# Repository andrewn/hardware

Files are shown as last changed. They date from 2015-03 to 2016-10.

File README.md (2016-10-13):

This repository contains a laser cutter template for a Radiodan case. 
See the `case` directory for the usage license and instructions.

It also contains the PCB design for Radiodan. Under the Gerber_Files 
directory are oshpark-radiodan and dirty-pcb-radiodan which we've 
successfully had made by OshPar and DirtyPCB respspectively.

Under the BOM directory are pdf and csv version of the Radiodan Bill of 
Materials as of October 2016.

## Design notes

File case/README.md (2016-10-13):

Case
----

A case suitable for laser cutter for making your own [radiodan](http://radiodan.net) case.

Photo of Radiodan case

The case is designed to be laser cut out of 3mm thickness material.

Our current recommendation is to use the wide case format, with [this BOM](https://github.com/radiodan/hardware/tree/master/bom).

We've used the following colours:

| Colour  | Action |
|---|---|
| RED | Cut |
| BLUE | Score  |
| BLACK | Etch |

[Follow our instructions](http://radiodan.net/help/tutorials/make-a-case.html) to put it all together.

Feedback
---

If you have any feedback or suggestions to make this design easier to use with a laser cutter then please [raise an issue](https://github.com/radiodan/hardware/issues).

License and adaptations
---

Please see [LICENSE](LICENSE.txt) for the terms about how you can use this design.

Credits
---

The case was designed by [Victor Johansson](https://twitter.com/victordons).

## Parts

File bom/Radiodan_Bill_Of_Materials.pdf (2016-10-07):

Radiodan Bill of Materials
2016-10-07
Description | RS code | Number | Part number | Link
26 PIN BOXED HEADER, VERTICAL, LOW PROFILE 461-786 | | 1 | THOMAS&BETTS 609-2627
RESISTOR,1%,120 ohm, MRS25, 683-2979 | | 2 | VISHAY BC COMPONENTS MRS25000C1200FCT00
RESISTOR,1%,68 ohm,MRS25, 683-3950 | | 4 | VISHAY BC COMPONENTS MRS25000C6809FCT00
SWITCH, MECHANICAL KEY686-6768 | | 1 | OMRON B3F-4050
SWITCH CAP,ROUND,BLACK682-1115 | | 1 | OMRON B32-1610
Raspberry PI 3 | 896-8660 | 1
8GB SD card | 917-6317 | 1
Power supply (2.5A) | 103-4302 | 1
ROTARY ENCODER - ILLUMINATED | | 2 | PPCOM-10982
Rotary encoder cap | | 2 | PPCOM-10597
GPIO downgrade ribbon cable | | 1 | | https://www.coolcomponents.co.uk/downgrade-gpio-ribbon-cable-for-raspberry-pi-model-b-40p-to-26p.html
DAC | | 1 | | https://shop.pimoroni.com/products/phat-dac
Speaker | | 1 | | https://www.amazon.co.uk/Veho-VSS-001-360-Portable-Rechargeable-Smartphones-Black/dp/B002CS2T4I
Extra tall stackable headers | | 1 | | https://www.coolcomponents.co.uk/stackable-header-20-pin.html
4cm length (minimum) bolts, 4mm diameter | | 4
Wingnuts | | 4
Sticky velcro | | a little | | http://www.ebay.co.uk/bhp/self-adhesive-velcro
Laser cut case | | 1 | | https://github.com/radiodan/hardware/tree/master/case
PCB | | 1 | | https://github.com/radiodan/hardware/tree/master/pcb

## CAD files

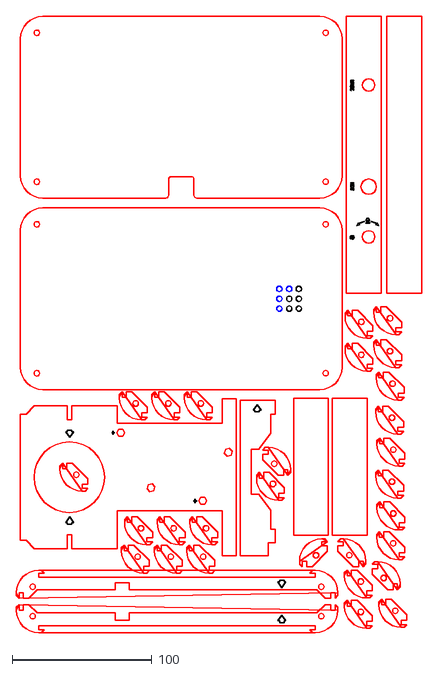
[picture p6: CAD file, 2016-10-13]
case/3mm Single Case - 0.25pt cut lines.dxf
290.0 x 440.7

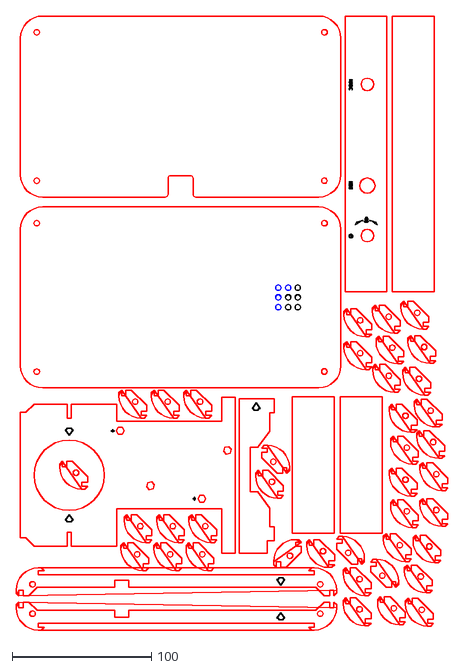
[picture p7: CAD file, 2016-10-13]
case/wide 3mm Single Case - 0.25pt cut lines.dxf
309.8 x 440.7

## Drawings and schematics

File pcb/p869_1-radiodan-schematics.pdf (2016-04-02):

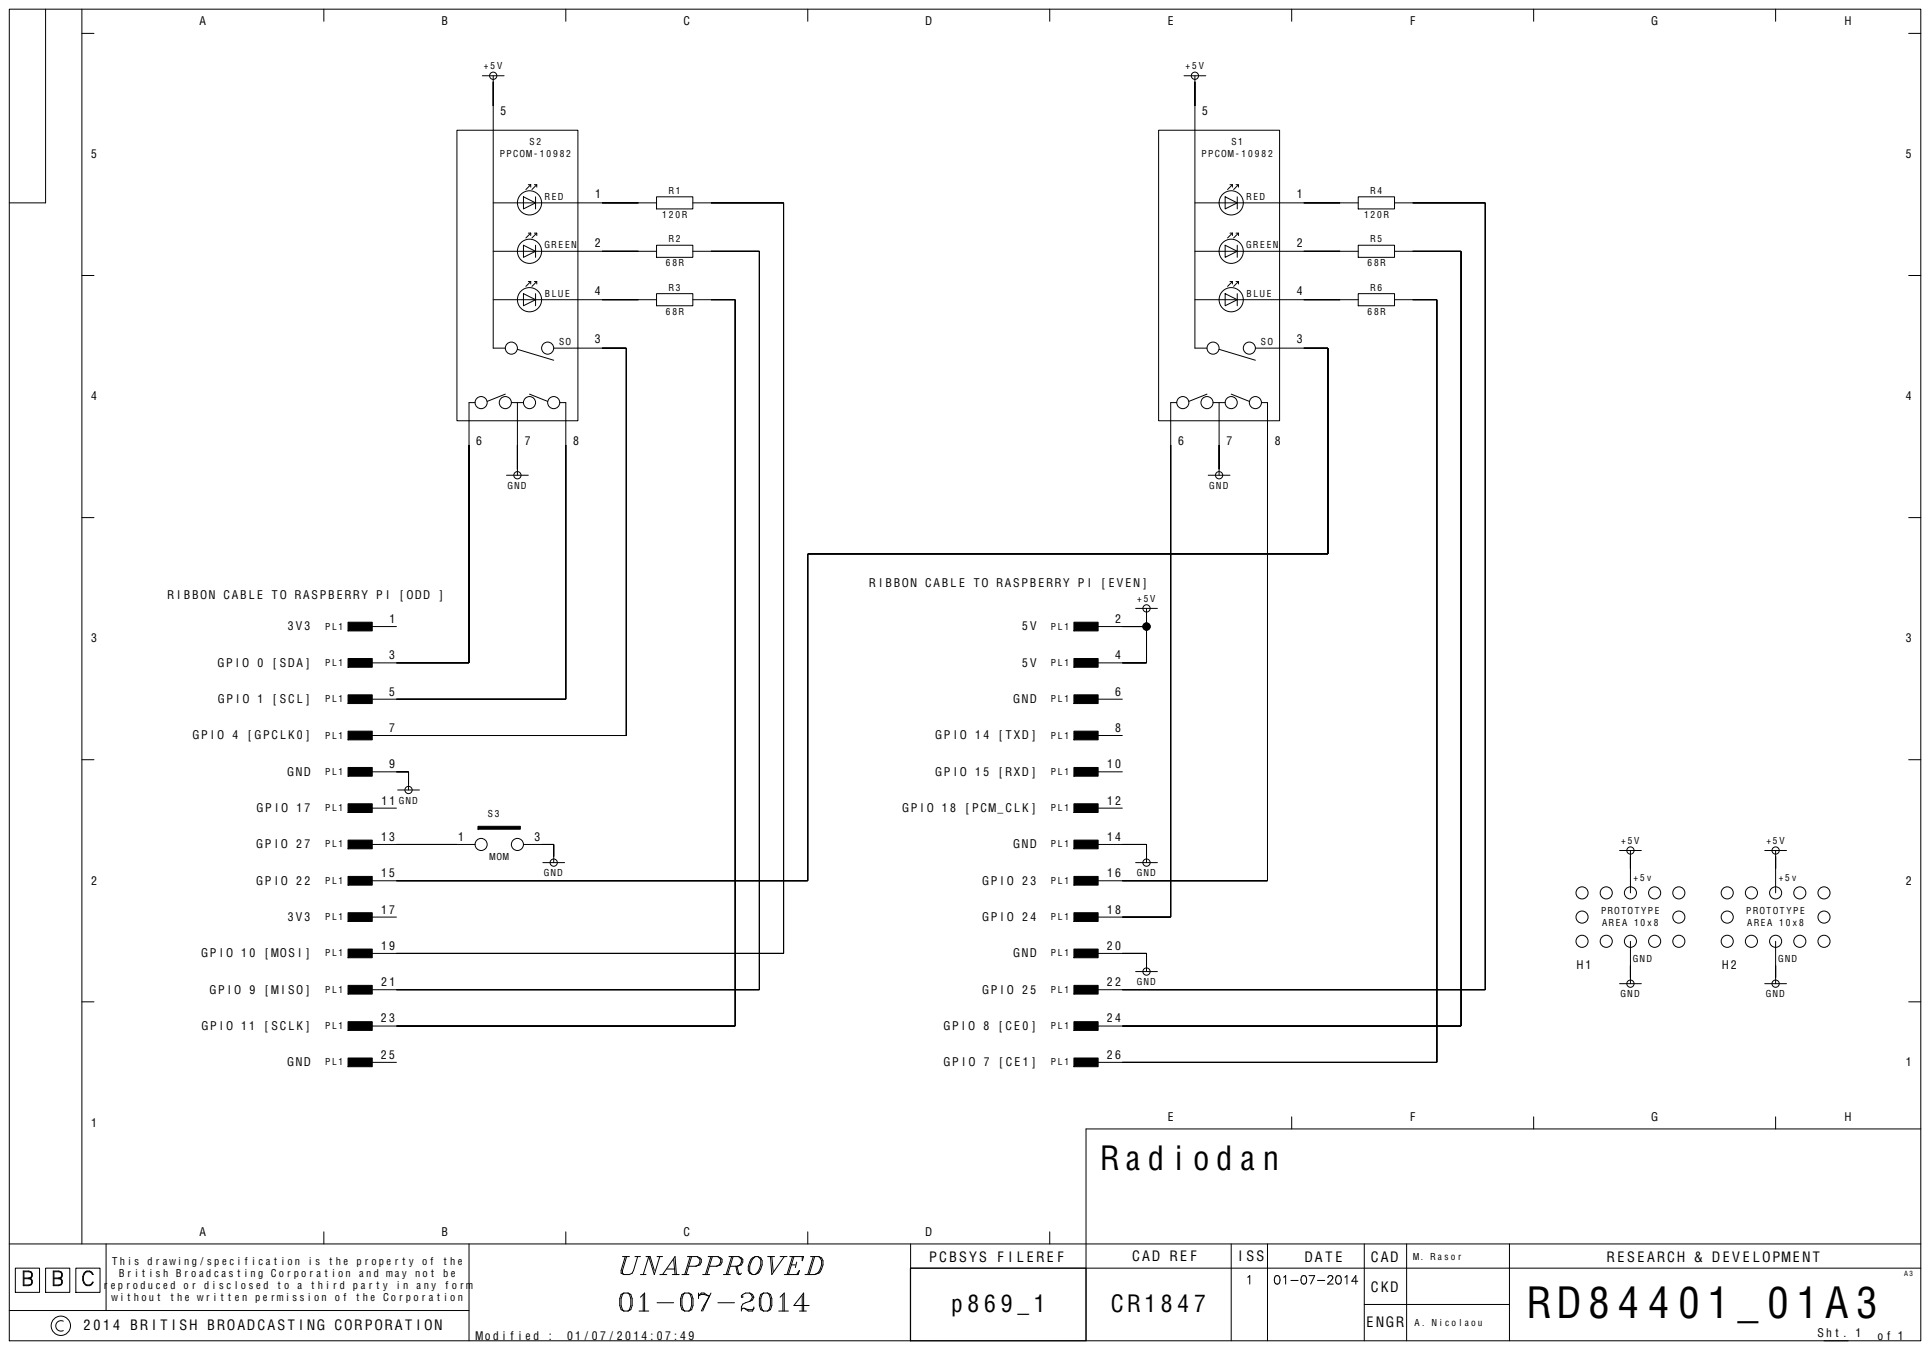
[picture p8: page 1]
R E S E ARCH & D E V E L OPME N T; E NGR; GND; GP I O 0 [ SDA ] P L 1; 9 GND P L 1; GP I O 1 0 [ MOS I ] P L 1; 2 5 GND P L 1; GND P L 1; GP I O 1 5 [ RXD ] P L 1; 2 0 GND P L 1; UNAPPROVED 01- 07- 2014; PRO T O T Y P E AR E A 1 0 x 8; MOM; P P COM - 1 0 9 8 2

R I B BON C A B L E T O RA S P B E RRY P I [ ODD ]

R I B BON C A B L E T O RA S P B E RRY P I [ E V E N ]

2 0 1 4 BR I T I SH BROADC A S T I NG CORPORA T I ON

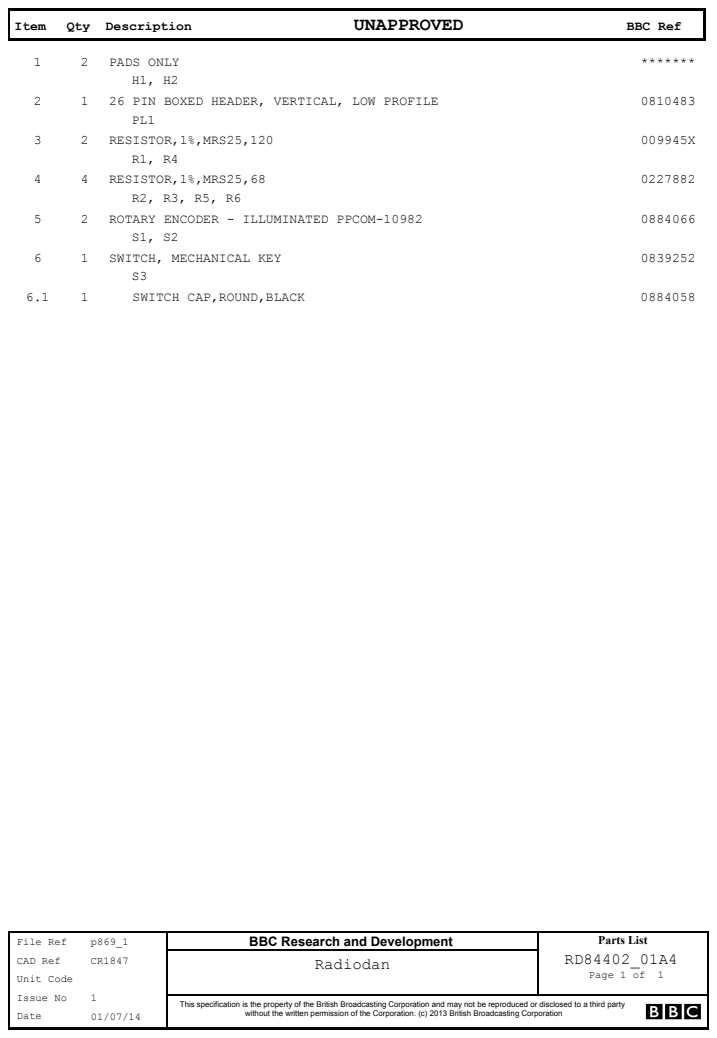
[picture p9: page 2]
Item; Qty Description; UNAPPROVED; BBC Ref; PADS ONLY; 26 PIN BOXED HEADER, VERTICAL, LOW PROFILE; RESISTOR,1%,MRS25,120; RESISTOR,1%,MRS25,68; ROTARY ENCODER - ILLUMINATED PPCOM-10982; SWITCH, MECHANICAL KEY; SWITCH CAP,ROUND,BLACK; Page 1 of 1; Issue No; Date; Unit Code; CAD Ref; Radiodan; File Ref; Parts List

BBC Research and Development

without the written permission of the Corporation. (c) 2013 British Broadcasting Corporation 01/07/14

This specification is the property of the British Broadcasting Corporation and may not be reproduced or disclosed to a third party

1

2

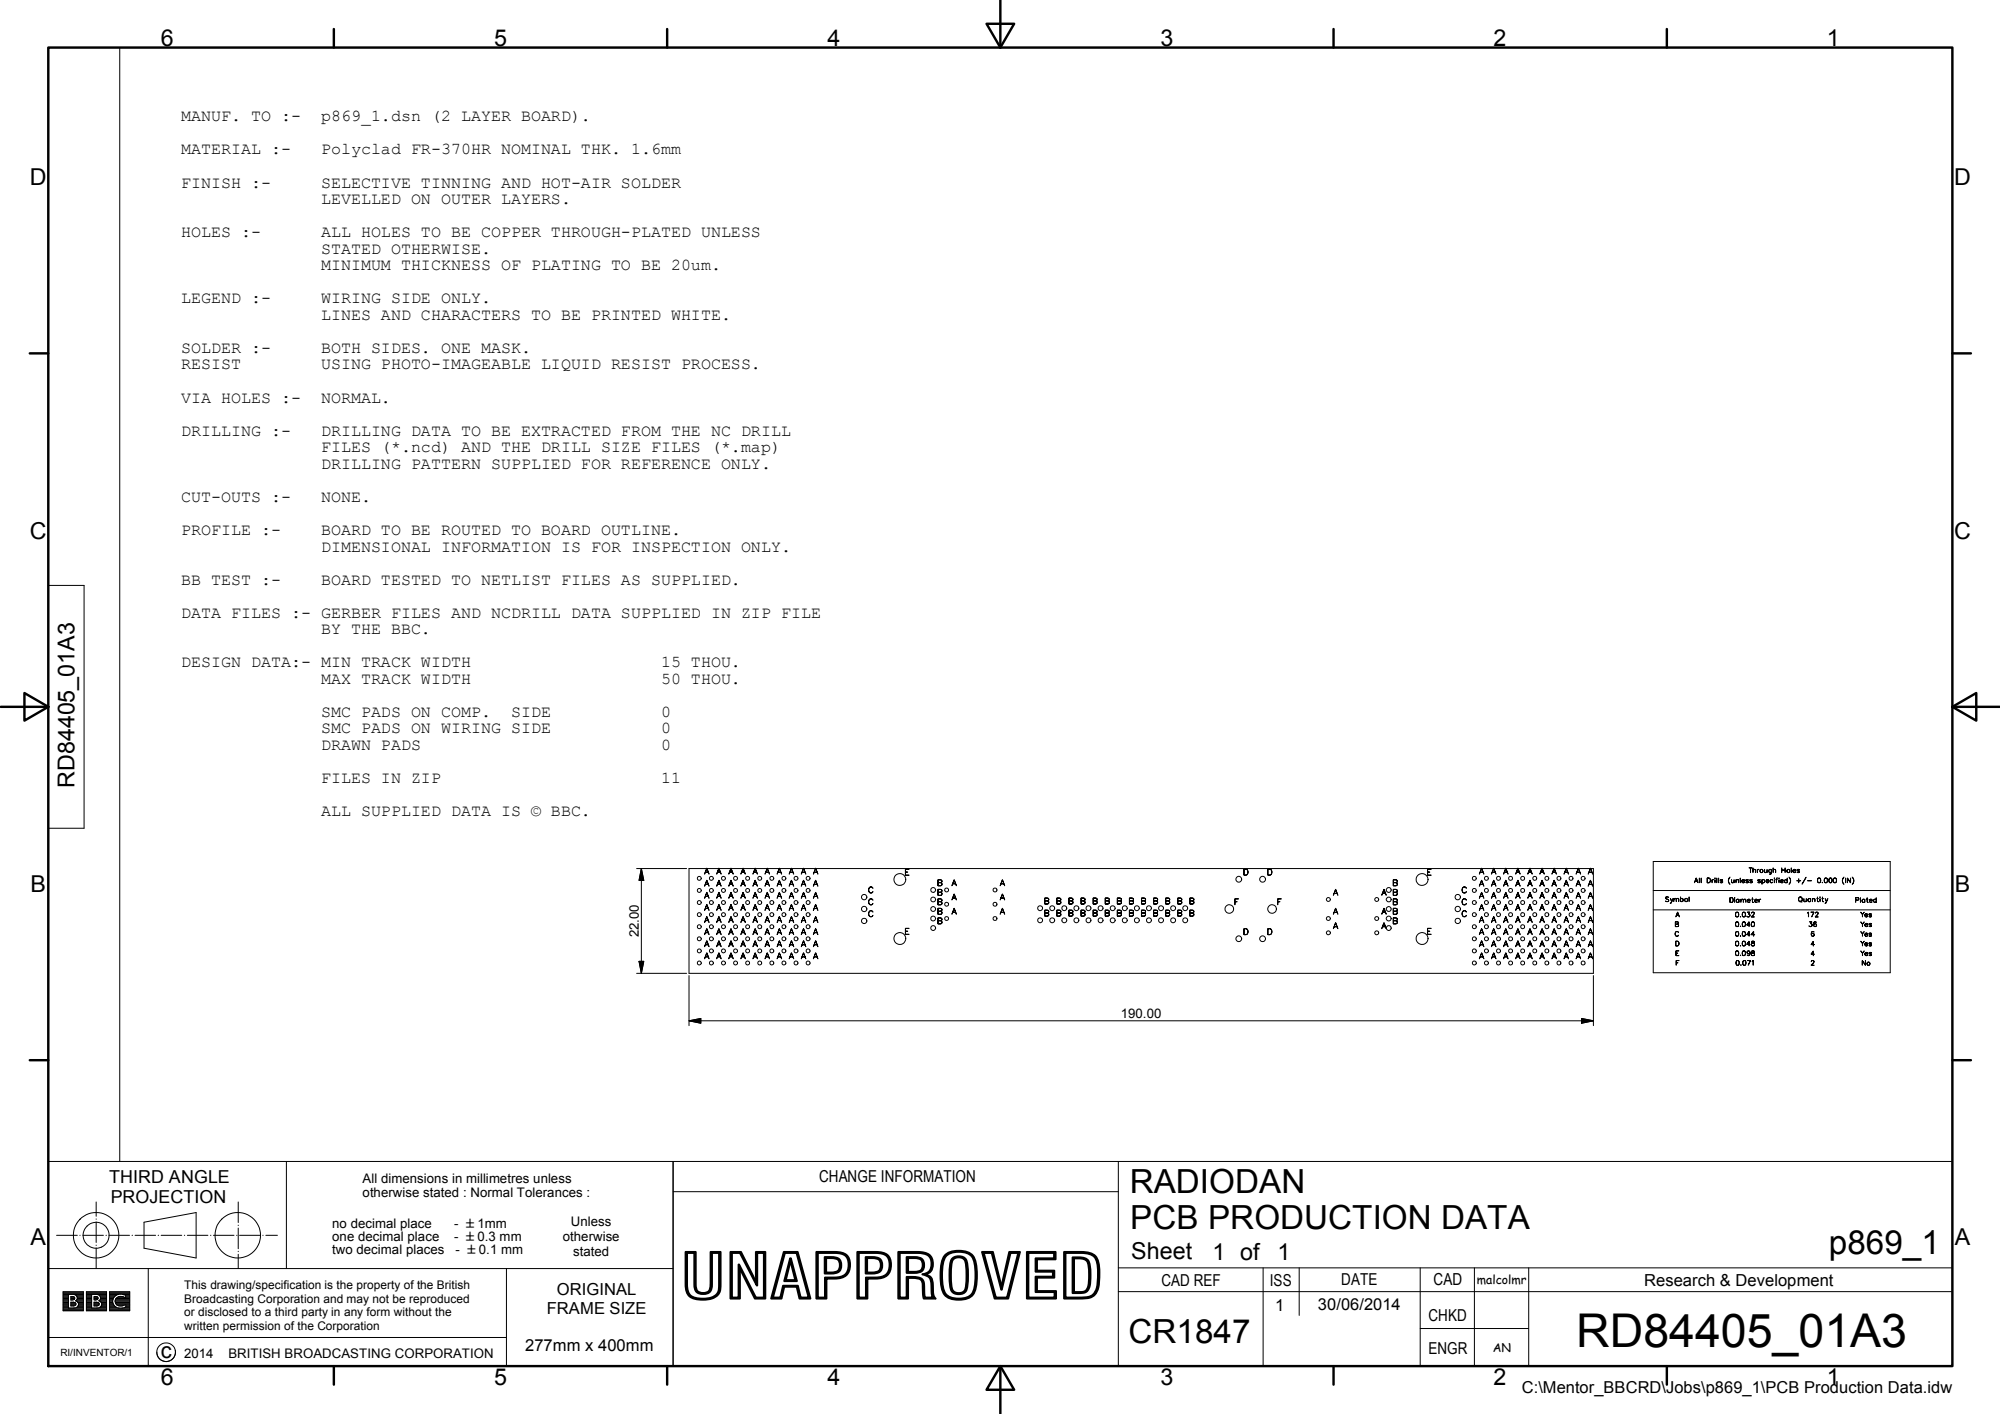
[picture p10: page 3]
Through Holes; Symbol; Diameter; Quantity; Plated; Yes; AAAAAAAAAA; BBBBBBBBBBBBB; THIRD ANGLE PROJECTION; no decimal place; Unless otherwise stated; CHANGE INFORMATION UNAPPROVED; MATERIAL :-; Polyclad FR-370HR NOMINAL THK. 1.6mm; FINISH :-; SELECTIVE TINNING AND HOT-AIR SOLDER; HOLES :-; ALL HOLES TO BE COPPER THROUGH-PLATED UNLESS; LEGEND :-; WIRING SIDE ONLY.; SOLDER :-; BOTH SIDES. ONE MASK.; RESIST; USING PHOTO-IMAGEABLE LIQUID RESIST PROCESS.; DRILLING :-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

MANUF. TO :- p869_1.dsn (2 LAYER BOARD).

LEVELLED ON OUTER LAYERS.

STATED OTHERWISE.
MINIMUM THICKNESS OF PLATING TO BE 20um.

LINES AND CHARACTERS TO BE PRINTED WHITE.

VIA HOLES :- NORMAL.

FILES (*.ncd) AND THE DRILL SIZE FILES (*.map)
DRILLING PATTERN SUPPLIED FOR REFERENCE ONLY.

DIMENSIONAL INFORMATION IS FOR INSPECTION ONLY.

DATA FILES :- GERBER FILES AND NCDRILL DATA SUPPLIED IN ZIP FILE

BY THE BBC.

ALL SUPPLIED DATA IS © BBC.

All Drills (unless specified) +/- 0.000 (IN)

All dimensions in millimetres unless
otherwise stated : Normal Tolerances :

RADIODAN
PCB PRODUCTION DATA
Sheet 1 of 1

one decimal place - B0.3 mm
two decimal places - B0.1 mm

This drawing/specification is the property of the British Broadcasting Corporation and may not be reproduced or disclosed to a third party in any form without the written permission of the Corporation | ORIGINAL FRAME SIZE 277mm x 400mm | CAD REF | ISS | DATE | CAD | malcolmr | Research & Development

CR1847 | | | CHKD | | RD84405_01A3

RI/INVENTOR/1 | c 2014 BRITISH BROADCASTING CORPORATION

ENGR | AN

C:\Mentor_BBCRD\Jobs\p869_1\PCB Production Data.idw

1

2

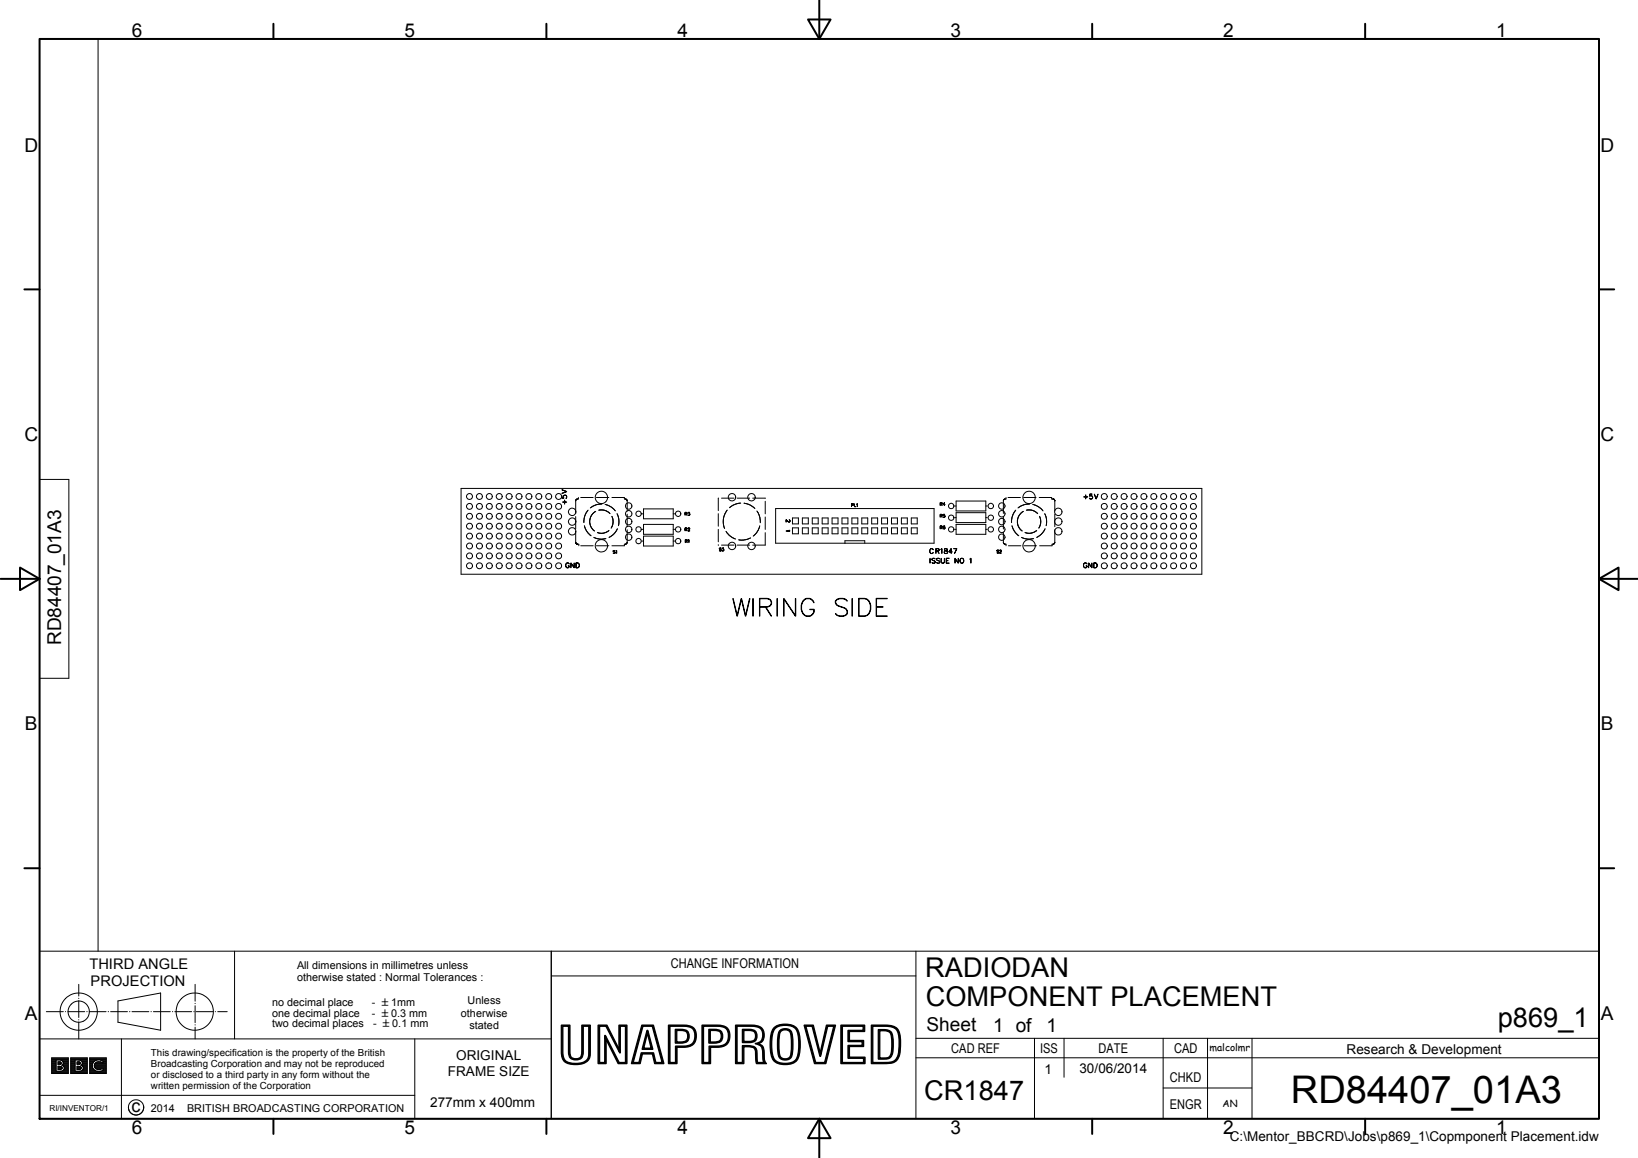
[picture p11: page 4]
WIRING SIDE; +5V GND GND +5V; ISSUE NO 1; THIRD ANGLE PROJECTION; no decimal place; Unless otherwise stated; RADIODAN COMPONENT PLACEMENT; CHANGE INFORMATION UNAPPROVED; Sheet 1 of 1

All dimensions in millimetres unless
otherwise stated : Normal Tolerances :

one decimal place - B0.3 mm
two decimal places - B0.1 mm

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

CR1847 | | | CHKD | | RD84407_01A3

RI/INVENTOR/1 | c 2014 BRITISH BROADCASTING CORPORATION

ENGR | AN

C:\Mentor_BBCRD\Jobs\p869_1\Copmponent Placement.idw

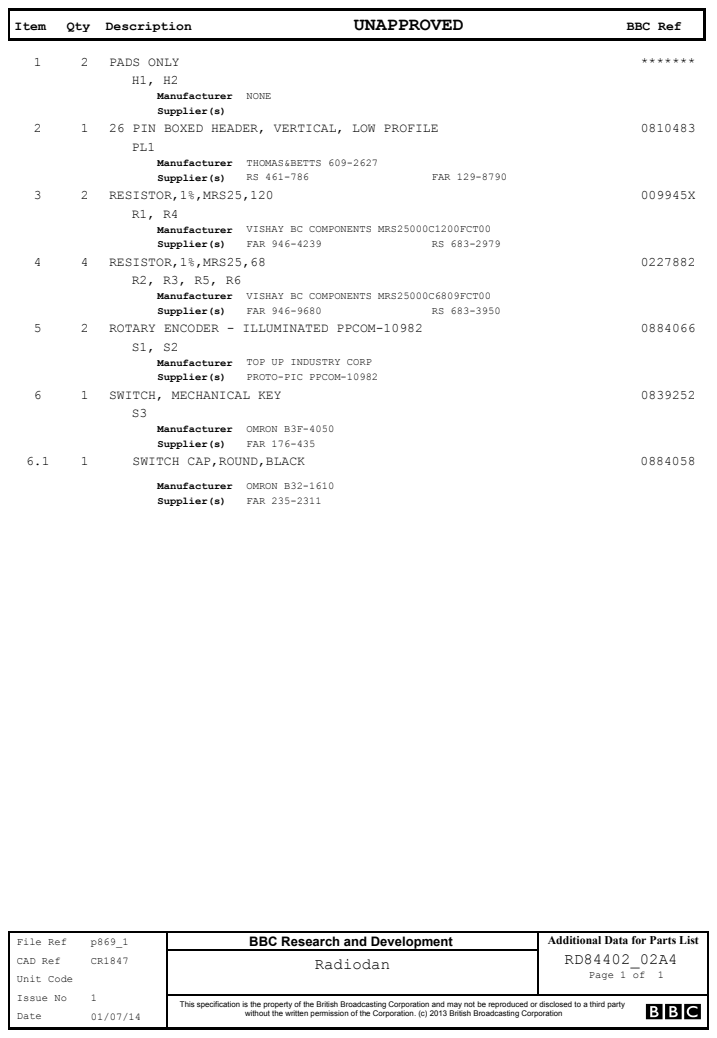
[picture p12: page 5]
Item; Qty Description; UNAPPROVED; BBC Ref; PADS ONLY; H1, H2 Manufacturer NONE Supplier(s); 26 PIN BOXED HEADER, VERTICAL, LOW PROFILE; THOMAS&BETTS 609-2627; FAR 129-8790; Manufacturer Supplier(s); RESISTOR,1%,MRS25,120; FAR 946-4239; RESISTOR,1%,MRS25,68; FAR 946-9680; ROTARY ENCODER - ILLUMINATED PPCOM-10982; S1, S2 Manufacturer Supplier(s); SWITCH, MECHANICAL KEY; OMRON B3F-4050 FAR 176-435; SWITCH CAP,ROUND,BLACK; OMRON B32-1610 FAR 235-2311; Page 1 of 1; Issue No; Date; Unit Code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

VISHAY BC COMPONENTS MRS25000C1200FCT00

VISHAY BC COMPONENTS MRS25000C6809FCT00

TOP UP INDUSTRY CORP
PROTO-PIC PPCOM-10982

BBC Research and Development

without the written permission of the Corporation. (c) 2013 British Broadcasting Corporation 01/07/14

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

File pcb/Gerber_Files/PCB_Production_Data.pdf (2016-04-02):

1

2

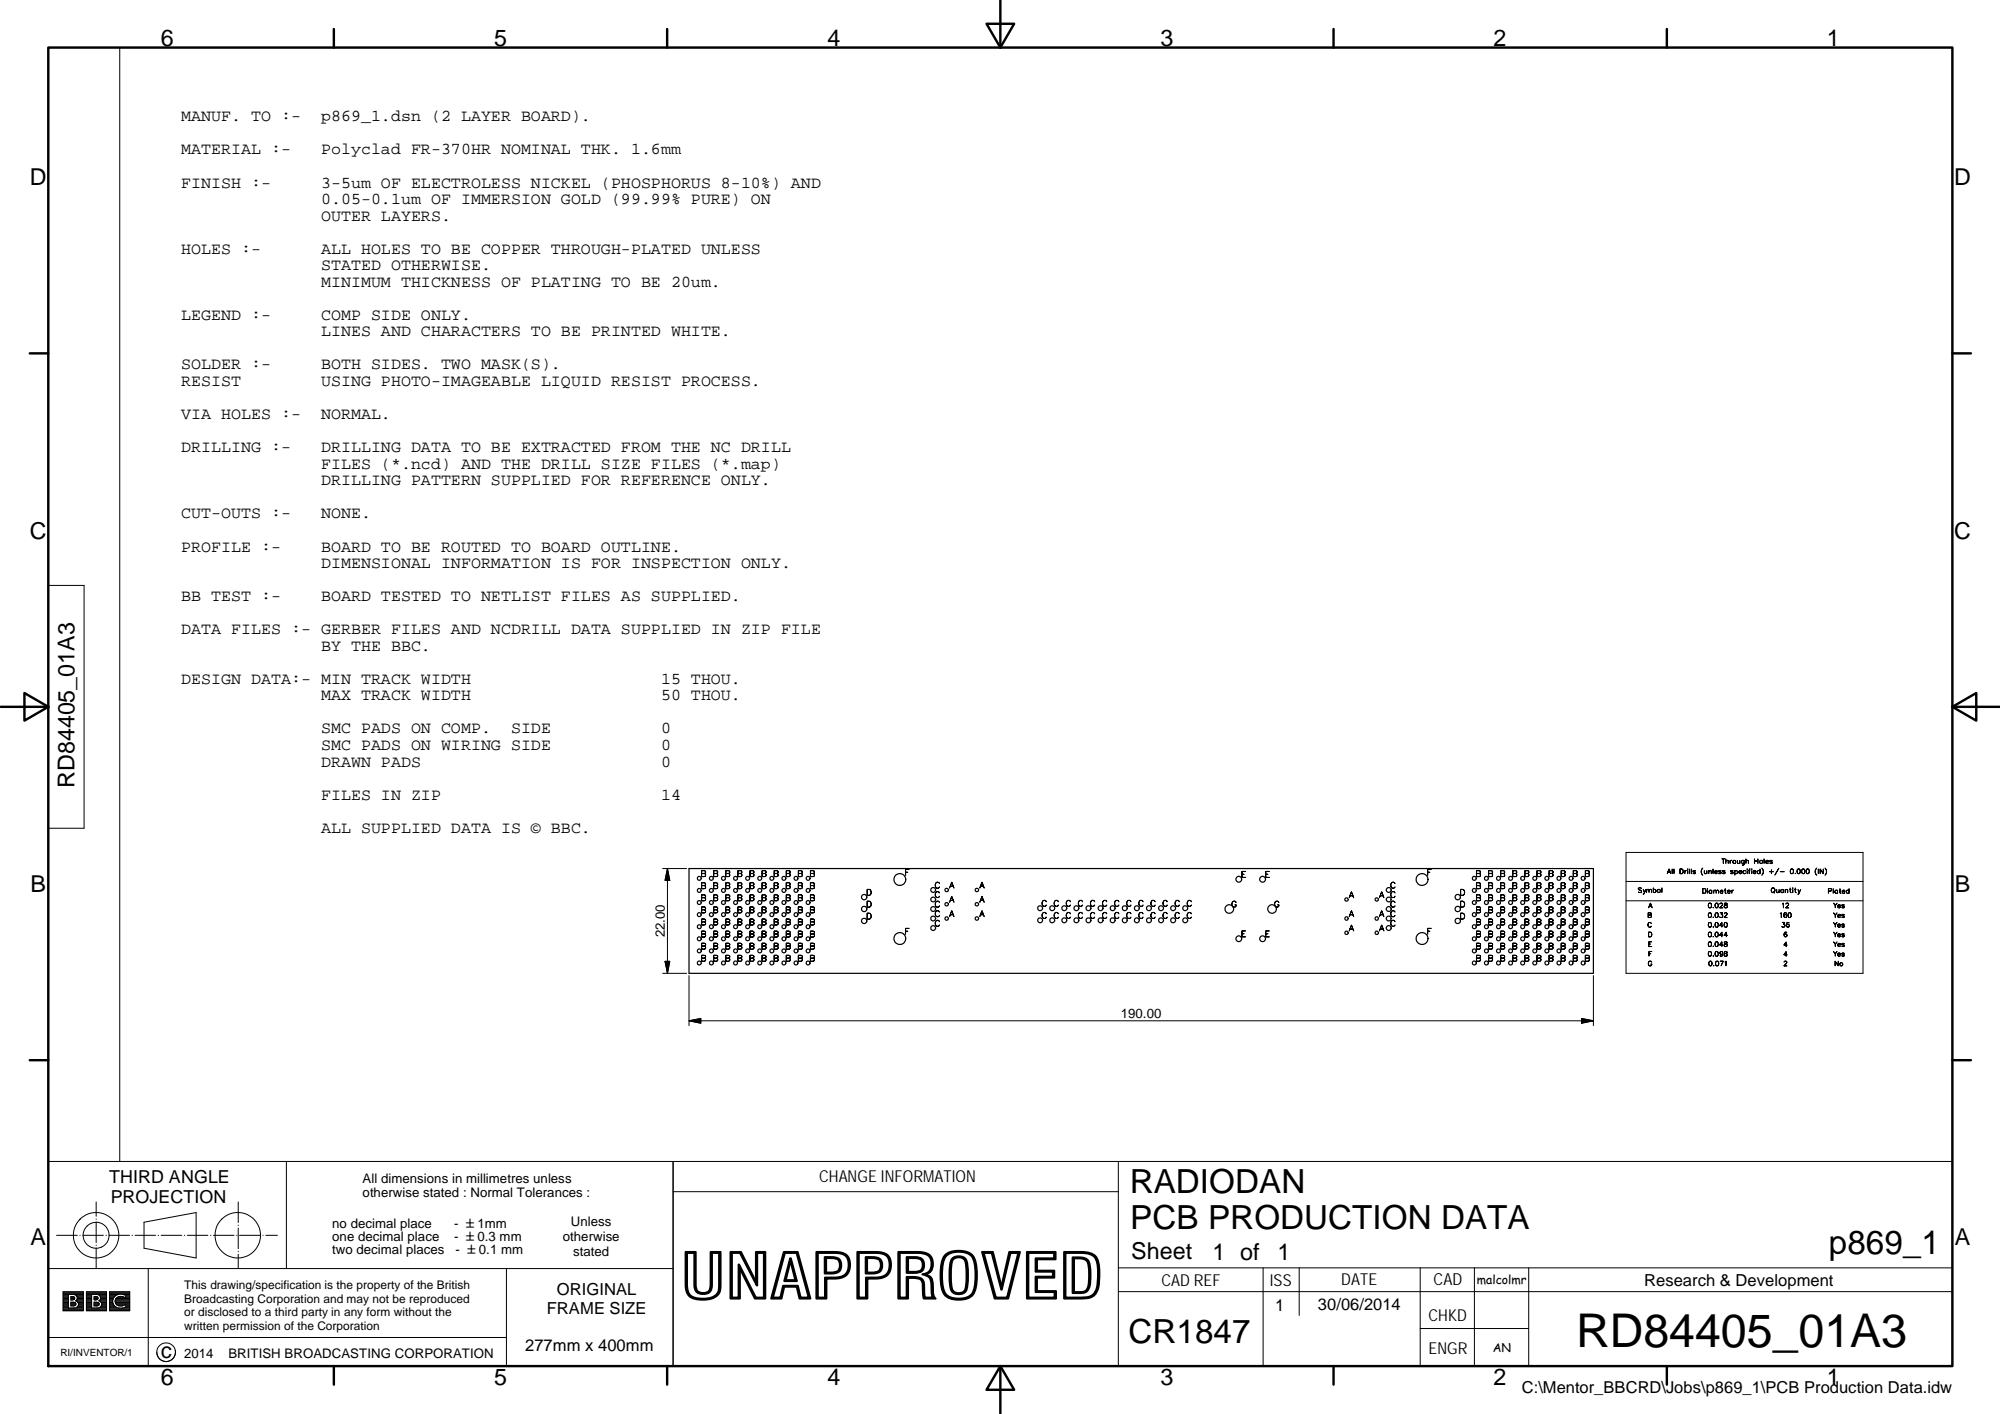
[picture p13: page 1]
Yes; Symbol; Diameter; Quantity; Plated; Through Holes; BBBBBBBBBB; CCCCCCCCCCCCC; THIRD ANGLE PROJECTION; no decimal place; Unless otherwise stated; CHANGE INFORMATION UNAPPROVED; MATERIAL :-; Polyclad FR-370HR NOMINAL THK. 1.6mm; FINISH :-; 3-5um OF ELECTROLESS NICKEL (PHOSPHORUS 8-10%) AND; HOLES :-; ALL HOLES TO BE COPPER THROUGH-PLATED UNLESS; LEGEND :-; COMP SIDE ONLY.; SOLDER :-; BOTH SIDES. TWO MASK(S).; RESIST; USING PHOTO-IMAGEABLE LIQUID RESIST PROCESS.; DRILLING :-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

MANUF. TO :- p869_1.dsn (2 LAYER BOARD).

0.05-0.1um OF IMMERSION GOLD (99.99% PURE) ON
OUTER LAYERS.

STATED OTHERWISE.
MINIMUM THICKNESS OF PLATING TO BE 20um.

LINES AND CHARACTERS TO BE PRINTED WHITE.

VIA HOLES :- NORMAL.

FILES (*.ncd) AND THE DRILL SIZE FILES (*.map)
DRILLING PATTERN SUPPLIED FOR REFERENCE ONLY.

DIMENSIONAL INFORMATION IS FOR INSPECTION ONLY.

DATA FILES :- GERBER FILES AND NCDRILL DATA SUPPLIED IN ZIP FILE

BY THE BBC.

ALL SUPPLIED DATA IS © BBC.

All Drills (unless specified) +/- 0.000 (IN)

All dimensions in millimetres unless
otherwise stated : Normal Tolerances :

RADIODAN
PCB PRODUCTION DATA
Sheet 1 of 1

one decimal place - 0.3 mm
two decimal places - 0.1 mm

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

CR1847 | | | CHKD | | RD84405_01A3

RI/INVENTOR/1 | c 2014 BRITISH BROADCASTING CORPORATION

ENGR | AN

C:\Mentor_BBCRD\Jobs\p869_1\PCB Production Data.idw

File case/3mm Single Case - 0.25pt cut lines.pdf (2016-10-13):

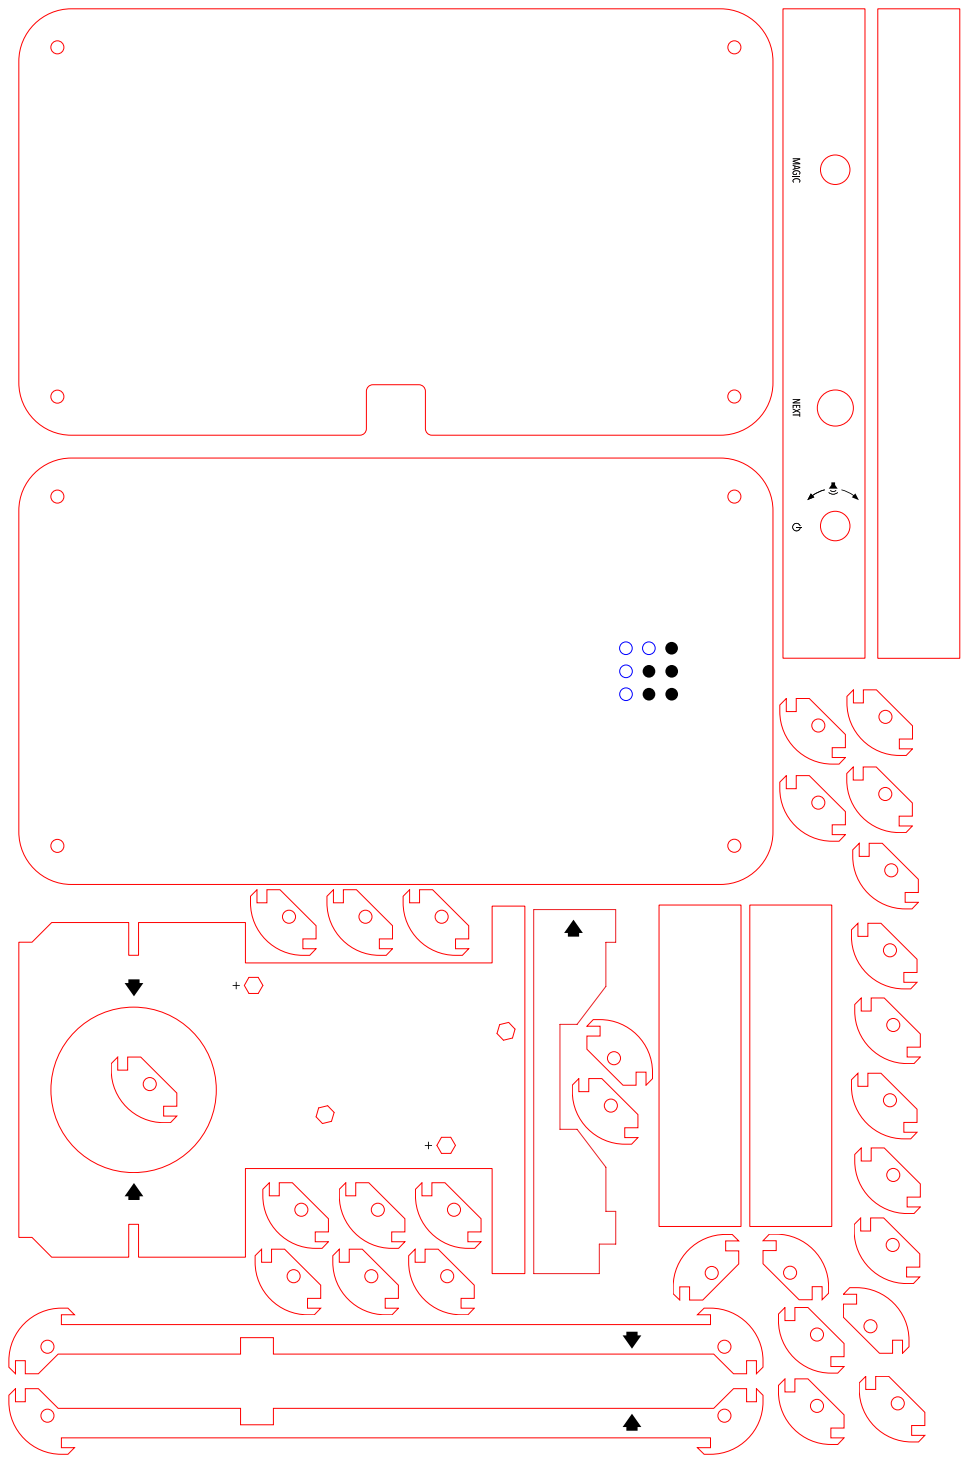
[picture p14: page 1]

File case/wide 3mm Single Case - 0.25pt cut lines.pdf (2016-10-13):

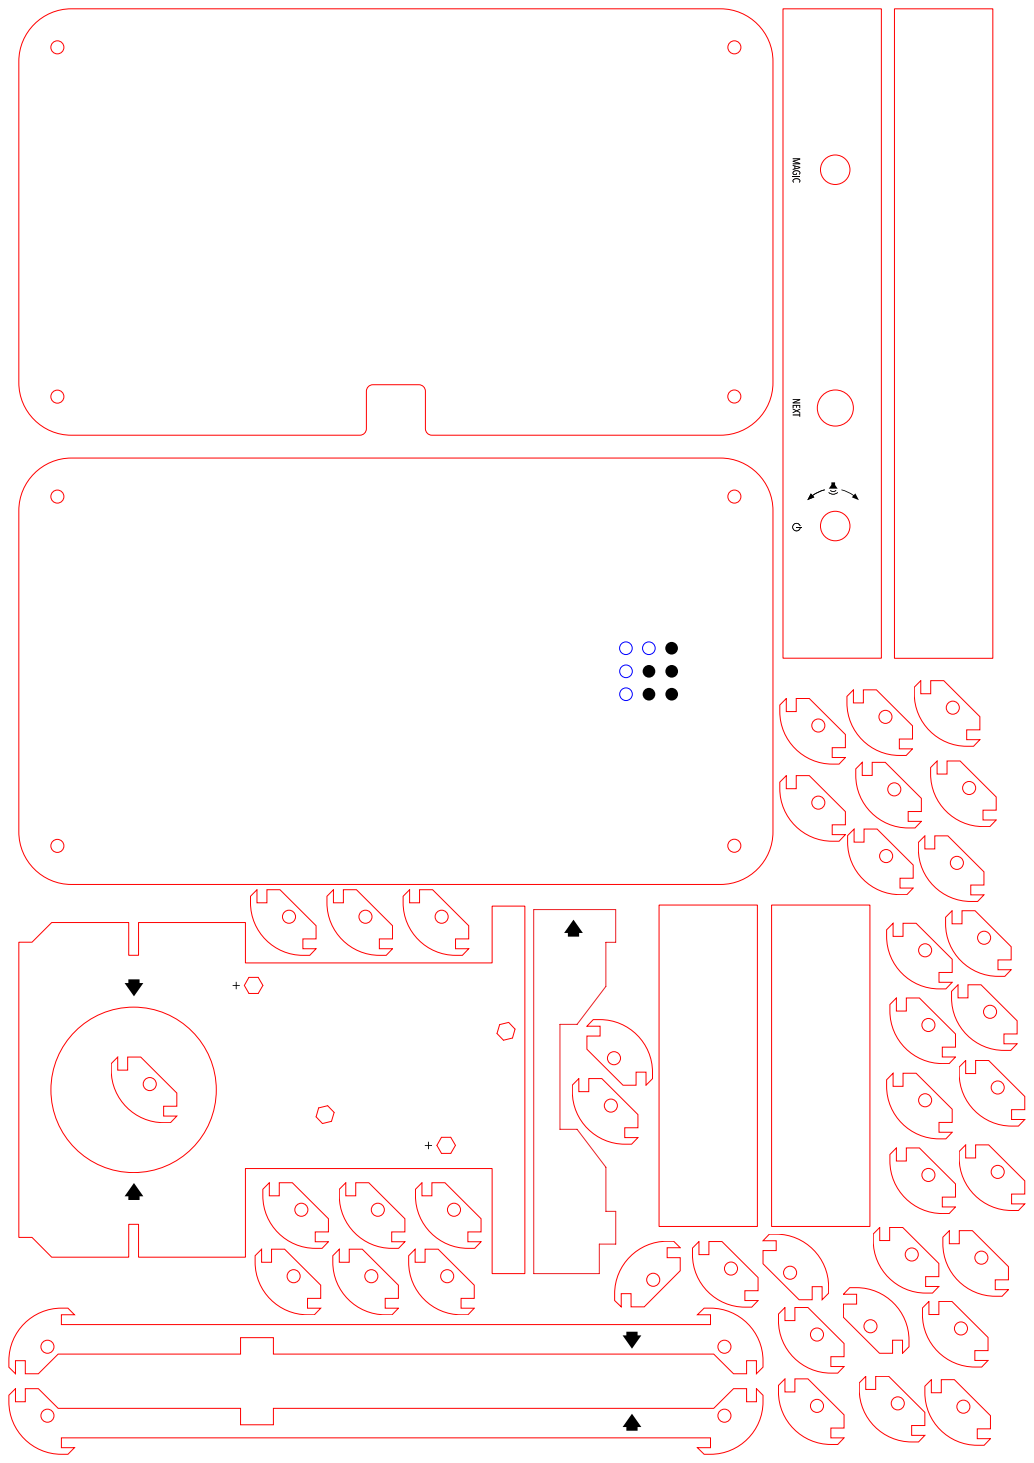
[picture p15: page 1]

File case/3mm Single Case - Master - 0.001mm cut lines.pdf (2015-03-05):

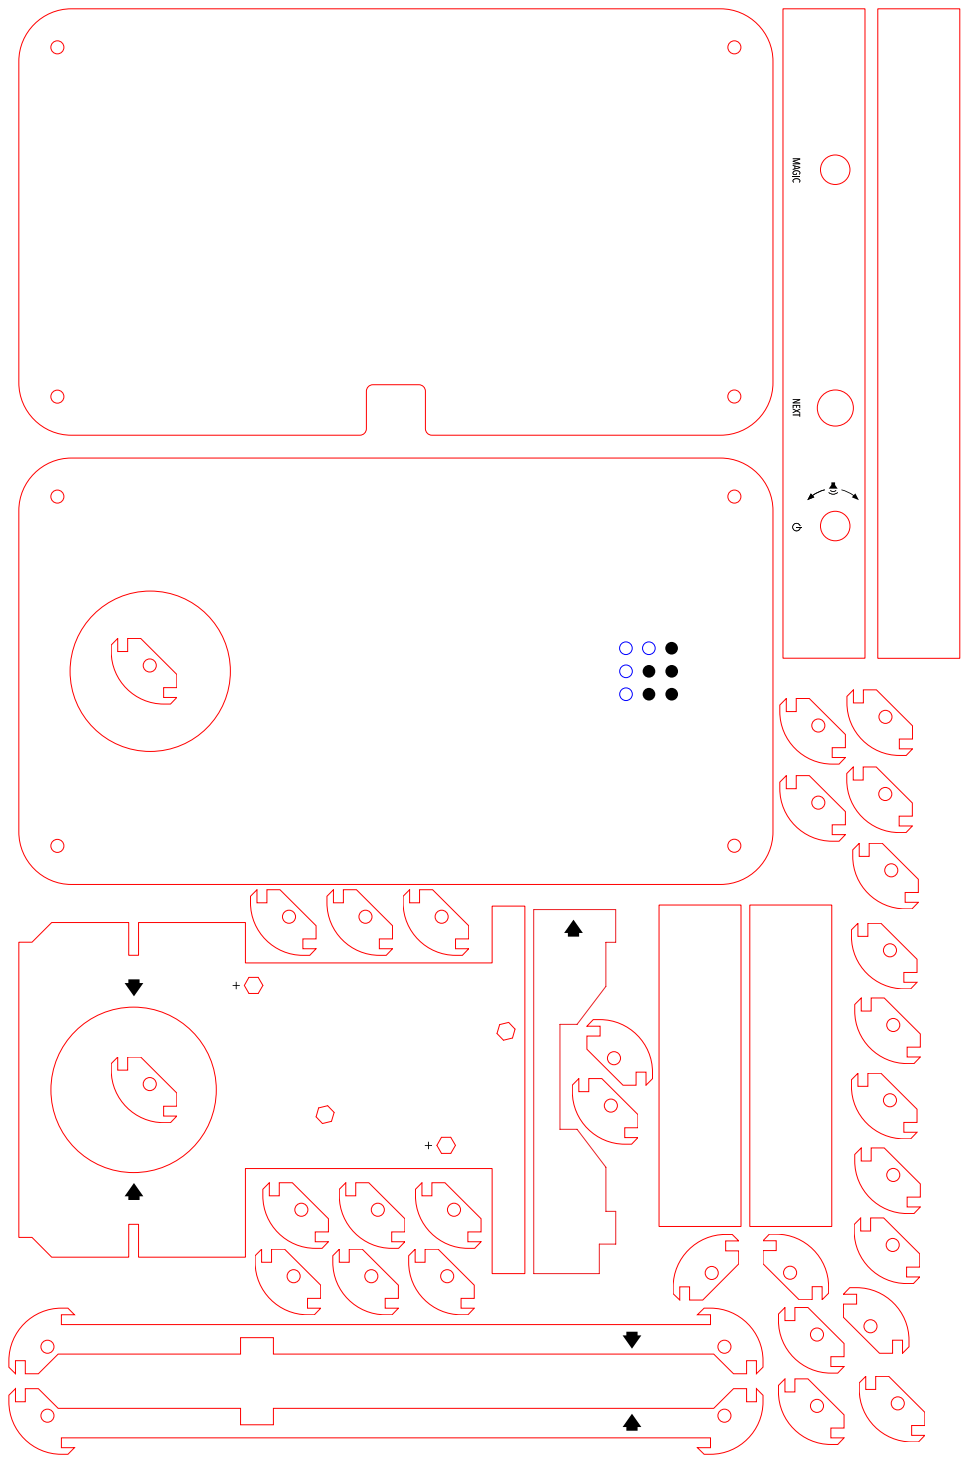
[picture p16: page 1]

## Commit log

2015-03-05 Initial commit of case design
2016-04-02 Added PCB designs
    [p869_1.dsn]
2016-04-30 Experimental OSH Park PCB files
    [BoardOutline.gbr, BoardOutline.gko, BottomSilkscreen.gbo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]
2016-07-04 Add dirty pcb files
    [BoardOutline.gko, BottomCopper.gbl, BottomSilkscreen.gbo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]
2016-10-07 Updated readme and added a recent bill of materials
    [Radiodan_Bill_Of_Materials.csv]
2016-10-13 Add new wider case
    [3mm Single Case - 0.25pt cut lines.dxf, wide 3mm Single Case - 0.25pt cut lines.dxf]
